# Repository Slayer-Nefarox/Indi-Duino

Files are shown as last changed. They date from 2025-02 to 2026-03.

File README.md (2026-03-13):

# Indi-Duino
Indi-Duino: uma alternativa para Sphero indi com Arduino Uno R3.

## Descrição
Este projeto consiste em um robô baseado em Arduino Uno R3 que utiliza um sensor de cores TCS34725 para interpretar cartões coloridos e mover-se conforme a cor detectada. O robô é equipado com uma ponte H para controle dos motores e pode acelerar, desacelerar, virar à direita ou à esquerda conforme os cartões.

Esta Branch será mantida como está, desde que é meu projeto origianl de conclusão de curso de graduação.
Todo e qualquer desenvolvimento e refino de funcionamento será feito na Branch V2.
Agradeço a todos que apoiaram essa luta.
A ideia sempre foi provar que para aqueles que sabem, sempre há uma alternativa á versão patenteada. 
E provado foi.

## Trabalho Descritivo do Processo de Criação (TCC - UFMS)
https://repositorio.ufms.br/handle/123456789/12544

## Especificações do Hardware

### Conexões:

#### Sensor de Cores (TCS34725) - Arduino Uno R3
- **VIn** → 5V
- **GND** → GND
- **SCL** → A5
- **SDA** → A4
- **LED** → 2

#### Ponte H - Arduino Uno R3
- **IN1** → 11
- **IN2** → 10
- **IN3** → 6
- **IN4** → 5

### Componentes Utilizados:
- **Arduino Uno R3**
- **Sensor de Cores Adafruit TCS34725**
- **Ponte H (L298N ou similar)**
- **Motores DC**
- **Cartões coloridos para controle do movimento**

## Dependências
Antes de carregar o código no Arduino, instale a biblioteca necessária:

```cpp
#include <Wire.h>
#include "Adafruit_TCS34725.h"
```

A biblioteca pode ser adicionada diretamente pela Arduino IDE 2.0 ou baixada do repositório oficial:
[Adafruit TCS34725 GitHub](https://github.com/adafruit/Adafruit_TCS34725)

## Funcionamento
O robô interpreta as cores detectadas pelo sensor e executa comandos específicos:
- **Verde** → Acelerar
- **Vermelho** → Desacelerar
- **Azul** → Virar à direita
- **Roxo** → Virar à esquerda

O código principal implementa essa lógica verificando os valores RGB detectados e comparando com as faixas predefinidas para cada cor.

## Código Explicado
### Definições de Hardware
```cpp
#define Mot_L_Frente 11
#define Mot_L_Tras 10
#define Mot_R_Frente 6
#define Mot_R_Tras 5
```
Define os pinos de controle dos motores.

### Parâmetros do Sistema
```cpp
#define Tempo 1500
#define intervalo 15
#define LedEnable 2
```
Controla o tempo de resposta e margem de erro para leitura de cores.

### Configuração do Sensor
```cpp
Adafruit_TCS34725 tcs = Adafruit_TCS34725(TCS34725_INTEGRATIONTIME_50MS, TCS34725_GAIN_60X);
```
Define os parâmetros do sensor de cores.

### Função de Debug
```cpp
void debug(float red, float green, float blue) {
  Serial.print("R:	"); Serial.print(int(red)); 
  Serial.print("	G:	"); Serial.print(int(green)); 
  Serial.print("	B:	"); Serial.print(int(blue));
  Serial.print("
");
}
```
Mostra os valores RGB no monitor serial para calibração.

### Lógica de Controle
- **Aceleração:**
```cpp
if(faixa( red, verde[0] ) && faixa(green, verde[1]) && faixa( blue, verde[2]) ) { 
    speed_mult += 2;
    analogWrite(Mot_L_Frente, speed_mult * speed_L);
    analogWrite(Mot_R_Frente, speed_mult * speed_R);
}
```
- **Desaceleração:**
```cpp
if(faixa( red, vermelho[0] ) && faixa(green, vermelho[1]) && faixa( blue, vermelho[2]) ) {
    speed_mult -= 2;
    analogWrite(Mot_L_Frente, speed_mult * speed_L);
    analogWrite(Mot_R_Frente, speed_mult * speed_R);
}
```
- **Virar à Direita:**
```cpp
if(faixa( red, azul[0] ) && faixa(green, azul[1]) && faixa( blue, azul[2]) ) {
    analogWrite(Mot_L_Frente, speed_mult * speed_L);
    analogWrite(Mot_R_Frente, 0);
    delay(tempo_delay);
}
```
- **Virar à Esquerda:**
```cpp
if(faixa( red, roxo[0] ) && faixa(green, roxo[1]) && faixa( blue, roxo[2]) ) {
    analogWrite(Mot_L_Frente, 0);
    analogWrite(Mot_R_Frente, speed_mult * speed_R);
    delay(tempo_delay);
}
```

## Conclusão
Este projeto permite que o robô se movimente de forma autônoma interpretando comandos por meio de cores, sendo uma solução acessível e eficaz para aplicações educacionais.

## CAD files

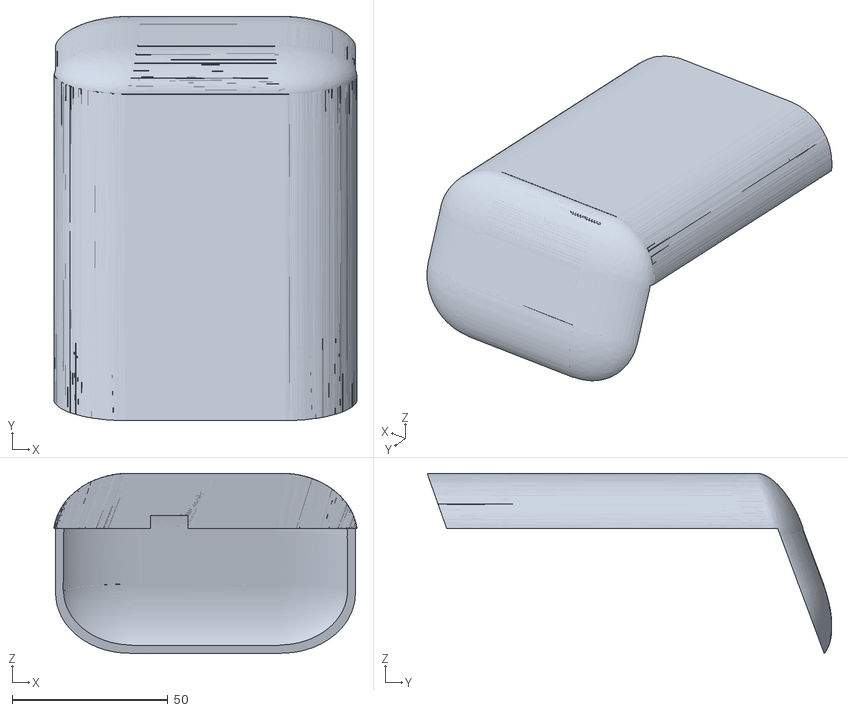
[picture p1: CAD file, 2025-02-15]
3D/Case/indi_uno_cap.stl
97.4 x 130.0 x 58.0

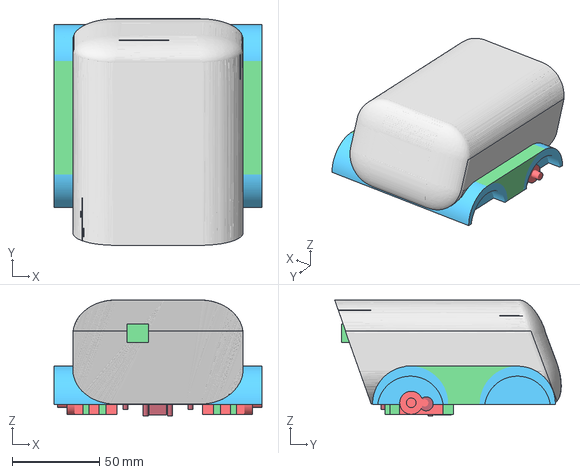
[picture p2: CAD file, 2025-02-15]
3D/Projeto_Montado.3mf
119.4 x 130.0 x 66.5 mm

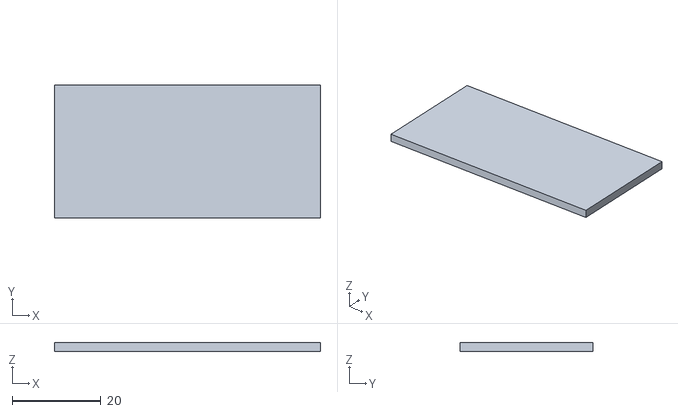
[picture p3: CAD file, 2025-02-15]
3D/wheels/indi proto base.stl
60.0 x 30.0 x 2.00

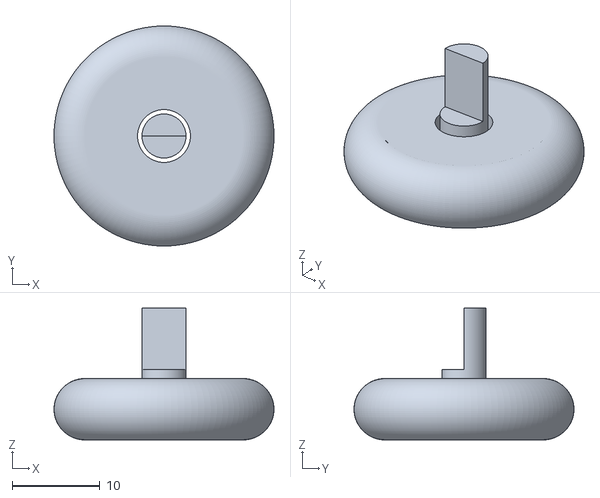
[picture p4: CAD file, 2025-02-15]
3D/wheels/front wheels.stl
25.0 x 25.0 x 15.0

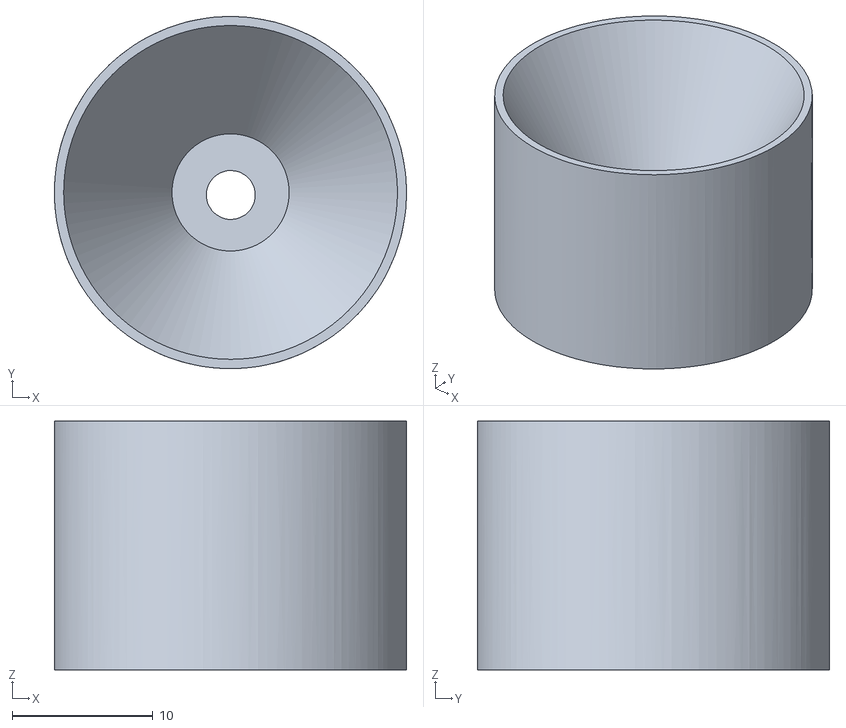
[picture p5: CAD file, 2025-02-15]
3D/wheels/back wheels.stl
25.0 x 25.0 x 17.7

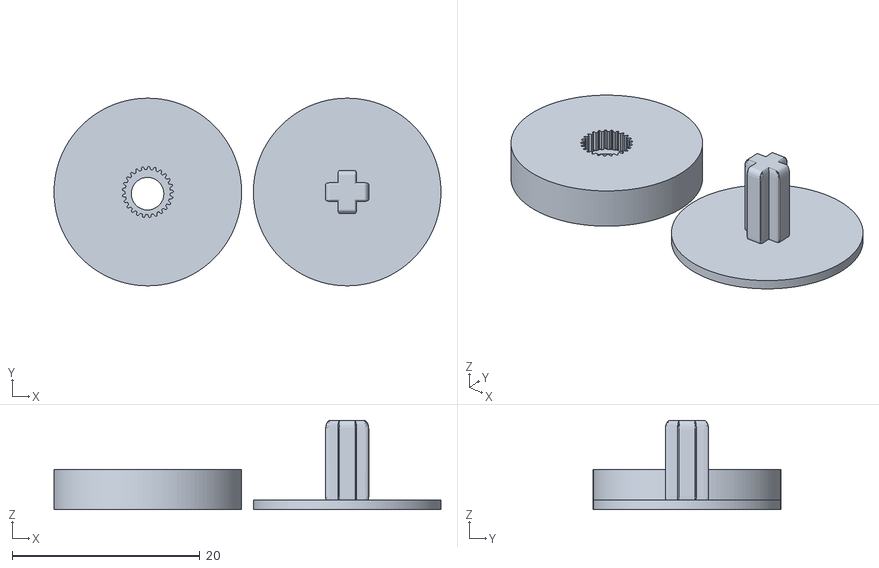
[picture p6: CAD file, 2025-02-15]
3D/wheels/back_wheels_lego_adapter.stl
41.3 x 20.0 x 9.50

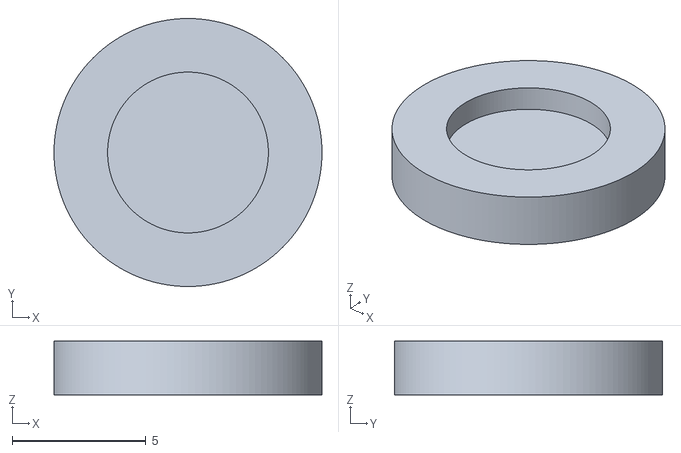
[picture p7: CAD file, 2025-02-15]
3D/wheels/Front_wheel_cap.stl
10.0 x 10.00 x 2.00

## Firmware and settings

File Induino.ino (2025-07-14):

//ligar os seguintes pinos:
//TCS3472 ----------- Arduino Uno R3
//VIn --------------- 5v
//Gnd --------------- Gnd
//Scl --------------- A5
//Sda --------------- A4
//Led --------------- 2

//Ponte H ----------- Arduino Uno R3
//in1 --------------- 11
//in2 --------------- 10
//in3 --------------- 6
//in4 --------------- 5

//Adicionar Biblioteca "Adafruit_TCS34725.h" ao Arduino IDE 2.0
//Possivel encontrar em https://github.com/adafruit/Adafruit_TCS34725
//adicionar via "bibliotecas" na arduino IDE 2.0 também é possivel, e BEM mais viável.


#include <Wire.h>
#include "Adafruit_TCS34725.h"

#define Mot_L_Frente 11
#define Mot_L_Tras 10
#define Mot_R_Frente 6
#define Mot_R_Tras 5

#define Tempo 1500 // tempo (em milissegundos) entre comandos

#define intervalo 15 // intervalo de tolerancia da faixa de cor

#define LedEnable 2 //pino que liga/desliga o led (caso use iluminação propria da placa)

Adafruit_TCS34725 tcs = Adafruit_TCS34725(TCS34725_INTEGRATIONTIME_50MS, TCS34725_GAIN_60X);// ganho possivel: X01, X04, X16, X60.

//variaveis globais
  //Velocidades individuais para cada motor para balancear imparidade de hardware. Minimo 1, máximo até 63.
int speed_L = 59;
int speed_R = 63;

int speed_mult = 0;
int ultima_Cor = 0;

//indice de cores
int verde[3] = {60,110,80};
int vermelho[3] = {150, 55,55};
int azul[3] = {28,86,131};
int roxo[3] = {103,51,94};
// ...

void debug(float red, float green, float blue)
{
  //debug valor do RGB
  Serial.print("R:\t"); Serial.print(int(red)); 
  Serial.print("\tG:\t"); Serial.print(int(green)); 
  Serial.print("\tB:\t"); Serial.print(int(blue));
  Serial.print("\n");
}

bool faixa(int var, int valor)
{
  if( var > valor-intervalo && var <= valor+intervalo )// se 'var' estiver dentro do intervalo levando em conta a margem de tolerância
  {
    return true;
  }
  else
  {
    return false;
  }
}

void setup() 
{
  Serial.begin(9600);
  pinMode(Mot_L_Frente, OUTPUT);
  pinMode(Mot_L_Tras, OUTPUT);
  pinMode(Mot_R_Frente, OUTPUT);
  pinMode(Mot_R_Tras, OUTPUT);

  analogWrite(Mot_L_Frente, 0);
  analogWrite(Mot_L_Tras, 0);

  analogWrite(Mot_R_Frente, 0);
  analogWrite(Mot_R_Tras, 0);
  
  if (tcs.begin()) 
  {
    Serial.println("Found sensor");
  } 
  else 
  {
    while (1) // ERRO
    {
      Serial.println("No TCS34725 found ... check your connections and reboot");
    }
  }

  pinMode(LedEnable, OUTPUT);
}

void loop() 
{
  digitalWrite(LedEnable, HIGH);// controle do LED
  float tempo_delay = Tempo;//estando mais rápido, precisa de menos tempo pra sair do cartão
  float red, green, blue;
  tcs.getRGB(&red, &green, &blue);

  if(faixa( red, verde[0] ) && faixa(green, verde[1]) && faixa( blue, verde[2]) ) //1: verde
  { 
    if(ultima_Cor != 1)
    {
      Serial.print("Frente ou acelera.");
      if(speed_mult<4)
      {
        speed_mult +=2;
        tempo_delay = Tempo / ((2/3)*speed_mult);//toda vez que atualizar a velocidade, atulizar o delay de virada
      }
      ultima_Cor = 1;
      delay(500);
      analogWrite(Mot_L_Frente, speed_mult*speed_L);
      analogWrite(Mot_L_Tras, 0); 
      analogWrite(Mot_R_Frente, speed_mult*speed_R);
      analogWrite(Mot_R_Tras, 0);
    }
    else
    {
      Serial.print("Frente ou acelera, Negado.");
    }
    
  }
  else if(faixa( red, azul[0] ) && faixa(green, azul[1]) && faixa( blue, azul[2]) ) //2: Azul
  { 
    if(ultima_Cor != 2)
    {
      Serial.print("Virar a direita.");
      ultima_Cor = 2;
      delay(500);
      analogWrite(Mot_L_Frente, speed_mult*speed_L);
      analogWrite(Mot_L_Tras, 0); 
      analogWrite(Mot_R_Frente, 0);
      analogWrite(Mot_R_Tras, 0); 
      delay(tempo_delay);//ajustar tempo_delay para virar 90 graus 
      analogWrite(Mot_L_Frente, speed_mult*speed_L);
      analogWrite(Mot_L_Tras, 0); 
      analogWrite(Mot_R_Frente, speed_mult*speed_R);
      analogWrite(Mot_R_Tras, 0);
    }
    else
    {
      Serial.print("Virar a direita, Negado.");
    }
    
  }
  else if(faixa( red, vermelho[0] ) && faixa(green, vermelho[1]) && faixa( blue, vermelho[2]) ) //3: vermelho
  { 
    if(ultima_Cor != 3)
    {
      Serial.print("Desacelera ou para.");
      if(speed_mult>0)
      {
        speed_mult -=2;
        tempo_delay = Tempo / ((2/3)*speed_mult);//toda vez que atualizar a velocidade, atulizar o delay de virada
      }
      ultima_Cor = 3;
      delay(500);
      analogWrite(Mot_L_Frente, speed_mult*speed_L);
      analogWrite(Mot_L_Tras, 0); 
      analogWrite(Mot_R_Frente, speed_mult*speed_R);
      analogWrite(Mot_R_Tras, 0);
    }
    else
    {
      Serial.print("Desacelera ou para, Negado.");
    }
    
  }
  else if(faixa( red, roxo[0] ) && faixa(green, roxo[1]) && faixa( blue, roxo[2]) ) //4: roxo
  { 
    if(ultima_Cor != 4)
    {
      Serial.print("Virar a esquerda.");
      delay(500);
      ultima_Cor = 4;
      analogWrite(Mot_L_Frente, 0);
      analogWrite(Mot_L_Tras, 0);
      analogWrite(Mot_R_Frente, speed_mult*speed_R);
      analogWrite(Mot_R_Tras, 0);
      delay(tempo_delay);//ajustar tempo_delay para virar 90 graus 
      analogWrite(Mot_L_Frente, speed_mult*speed_L);
      analogWrite(Mot_L_Tras, 0);
      analogWrite(Mot_R_Frente, speed_mult*speed_R);
      analogWrite(Mot_R_Tras, 0);
    }
    else
    {
      Serial.print("Virar a esquerda, Negado.");
    }
  }
  else //nenhuma cor cadastrada
  {
    Serial.print("Nenhuma cor detectada entre as cadastradas.");
    ultima_Cor = 0;
  }
  //modelo de estrutura para adicionar cores
  /*
  else if(faixa( red, cor[0] ) && faixa(green, cor[1]) && faixa( blue, cor[2]) ) // cor
  { 
    Serial.print("frente");
    analogWrite(Mot_L_Frente, 200);
    analogWrite(Mot_L_Tras, 0); 
    analogWrite(Mot_R_Frente, 200);
    analogWrite(Mot_R_Tras, 0); 
    delay(tempo_delay);
  }
  */
  debug(red, green, blue);
}
